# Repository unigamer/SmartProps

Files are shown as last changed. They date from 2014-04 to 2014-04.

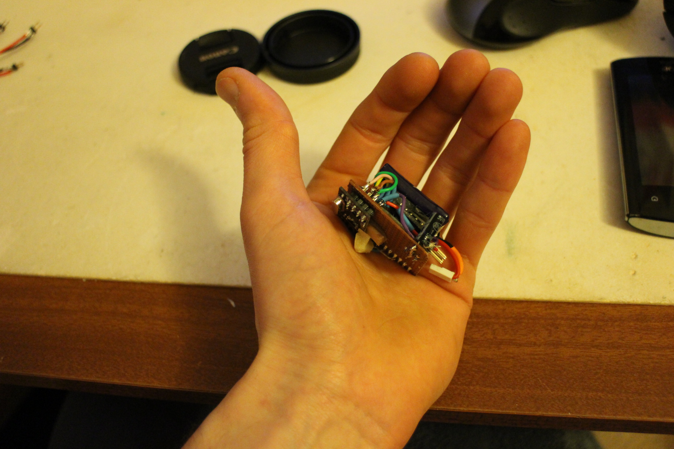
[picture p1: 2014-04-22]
Juggling Balls/Schematics/Ball PCB - Draft 1/IMG_0808.JPG

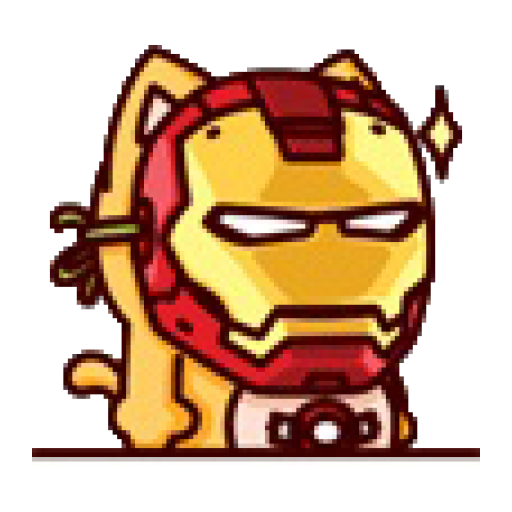
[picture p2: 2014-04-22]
Juggling Balls/Ball Control (GUI) Code/Android/ic_launcher-web.png

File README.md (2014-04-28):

SmartProps
==========

Smart LED circus props

Demo: https://www.youtube.com/watch?v=CMix5ZxQXCQ&feature=youtu.be

You want open source, smart, bluetooth enabled, LED juggling props?! Well, you're at the right place. However, this project is very much in its infancy. You can't buy any props and even making them is a bit tricky just now. I still think the code should be available so it's all here.

What can your juggling balls do?
The juggling balls are wirelessly connected and can detect if they are in your hand or in the air. A simple effect is changing colour every time they are thrown. A more advanced version is when all balls thrown at an instance change to the same random colour. The balls can flash and fade as well as staying a solid colour. All of this can be controlled through your computer or bluetooth-enabled Android phone. No more annoying button tapping to program your props! :)

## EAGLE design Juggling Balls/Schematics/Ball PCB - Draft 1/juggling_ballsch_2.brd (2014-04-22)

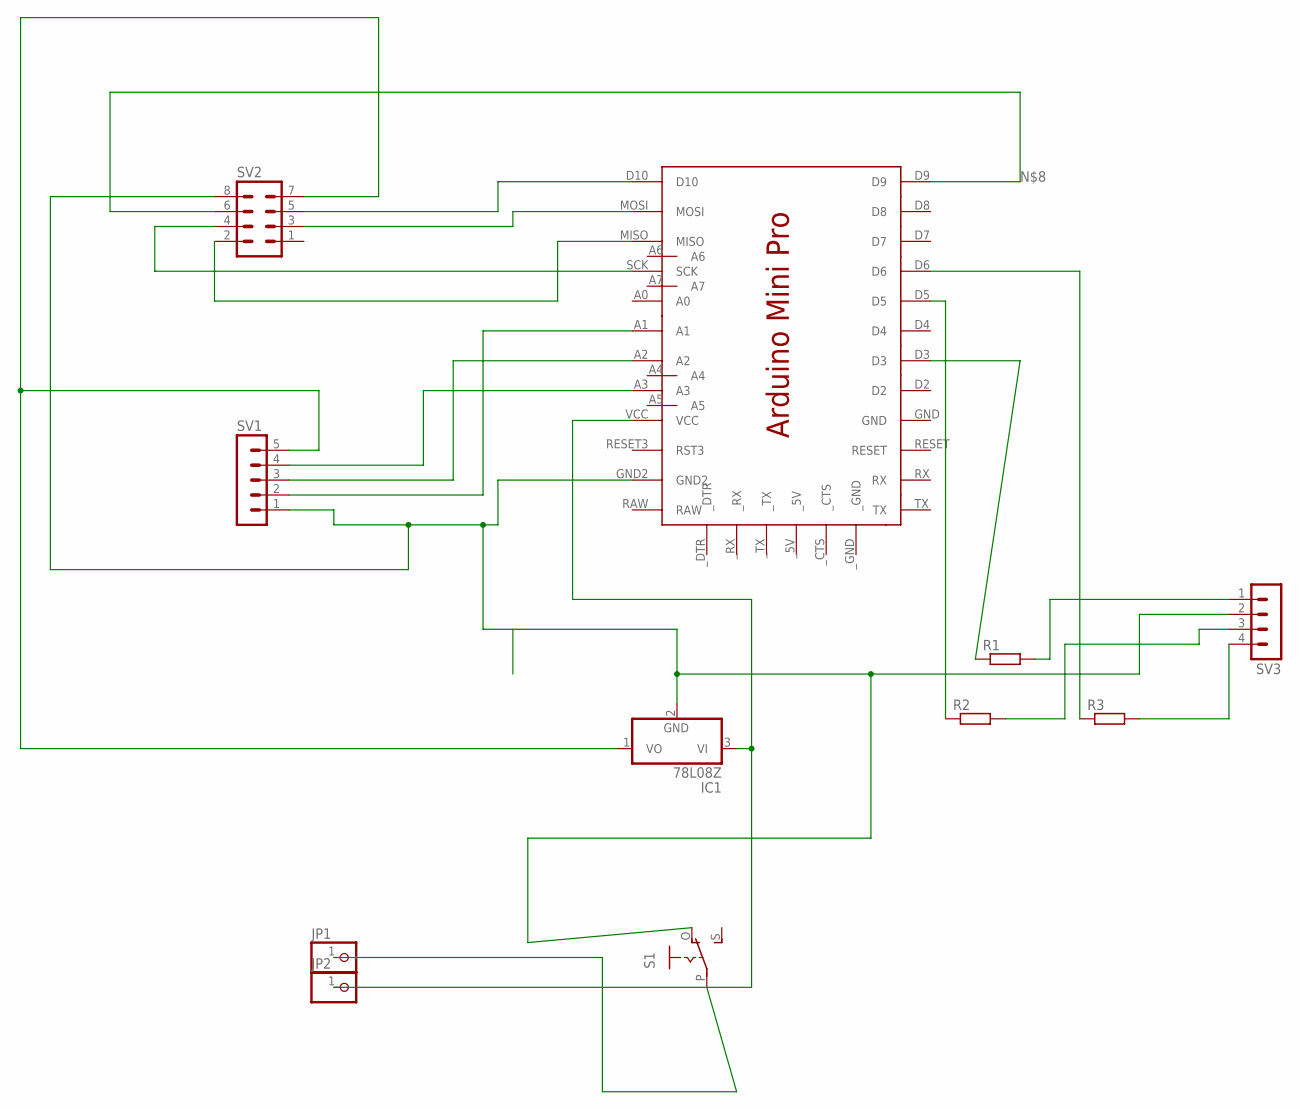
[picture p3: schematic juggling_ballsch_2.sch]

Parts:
IC1: 78L08Z; TO92
JP1, JP2: PINHD-1X1; 1X01
R1, R2, R3: R-EU_0207/7; 0207/7
S1: EG1218S; EG1218
SV1: MA05-1
SV2: MA04-2
SV3: MA04-1
U$1: ARDMINIPRO

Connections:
unnamed: SV1.2, U$1.A1
unnamed: SV1.3, U$1.A2
unnamed: SV1.4, U$1.A3
unnamed: IC1.2 (GND), S1.O, SV1.1, SV2.8, SV3.2, U$1.GND2
unnamed: SV2.3, U$1.MOSI
unnamed: SV2.5, U$1.D10
unnamed: SV2.2, U$1.MISO
unnamed: SV2.6, U$1.D9
unnamed: SV2.4, U$1.SCK
unnamed: IC1.1 (VO), SV1.5, SV2.7
unnamed: R1.1, U$1.D3
unnamed: R2.1, U$1.D5
unnamed: R3.1, U$1.D6
unnamed: R1.2, SV3.1
unnamed: R2.2, SV3.3
unnamed: R3.2, SV3.4
unnamed: JP1.1, S1.P
unnamed: IC1.3 (VI), JP2.1, U$1.VCC

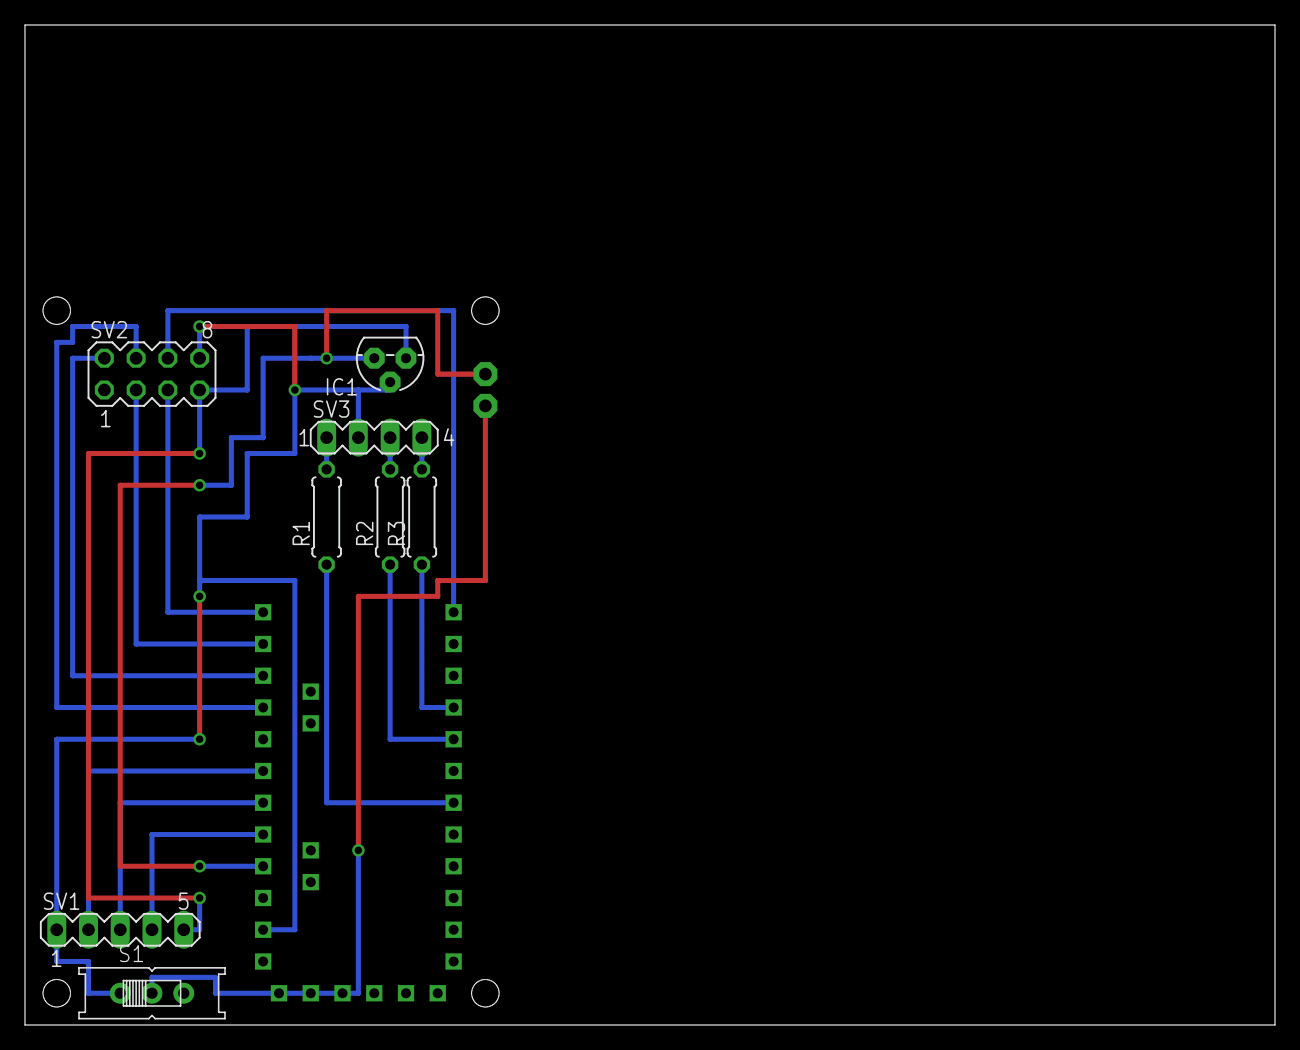
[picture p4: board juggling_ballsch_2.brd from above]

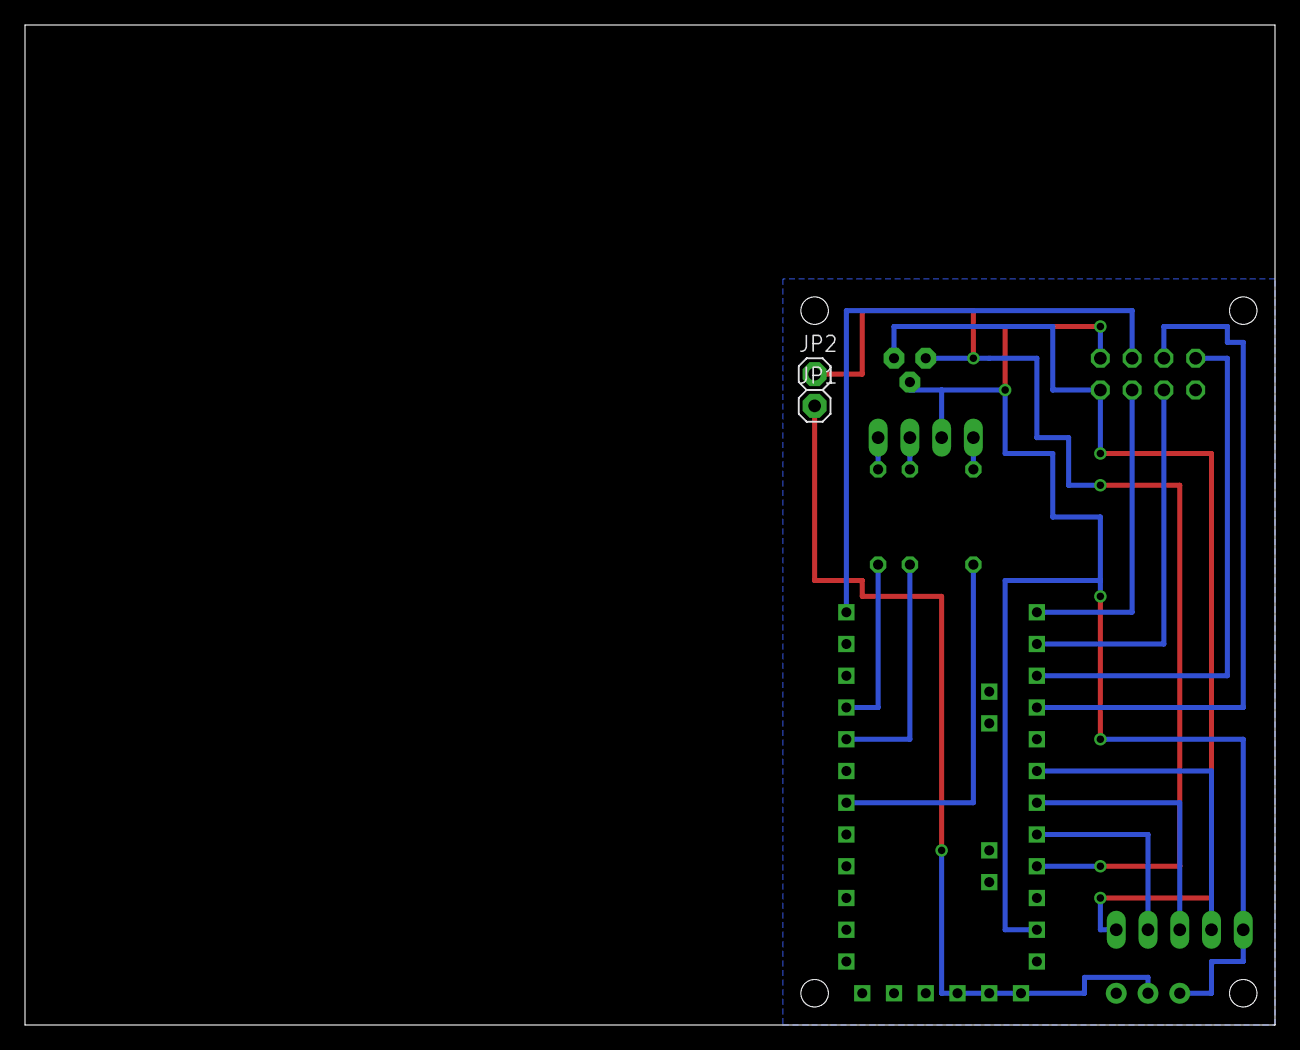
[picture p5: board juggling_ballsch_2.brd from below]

Board: 2 copper layers, 100.0 x 80.0 mm, 11 parts (2 on the bottom side), 18 nets.

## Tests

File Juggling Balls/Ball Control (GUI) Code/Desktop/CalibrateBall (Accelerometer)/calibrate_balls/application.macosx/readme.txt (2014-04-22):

This application was created on Windows, which does not
properly support setting files as "executable",
a necessity for applications on Mac OS X.

To fix this, use the Terminal on Mac OS X, and from this
directory, type the following:

chmod +x calibrate_balls.app/Contents/MacOS/JavaApplicationStub

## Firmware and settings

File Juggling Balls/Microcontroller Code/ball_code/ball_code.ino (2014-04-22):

// Juggling Ball Code
// Jonathan Jamieson
// unigamer@gmail.com
// www.jonathanjamieson.com

/*
How to send a command to a juggling ball

An ASCII string of comma seperated values should be sent either through the bluetooth>serial module or the 
USB>Serial converter on the central node. There needs to be 14 numbes terminated by a newline "/n". An
example command that would set ball number 1 to red is: 1,1,1,1,255,0,0,0,0,0,0,0,0,0

The structure is:

"1:Central Node Command Type, 2:Ball Number, 3:Ball Command Type, 4:Effect Number, 5:Red 1, 6:Green 1, 7:Blue 1, 8:Red 2, 9:Green 2, 10:Blue 2, 11:Fade Delay, 12:Send State, 13:Unused, 14: Unused"

1. Central Node Command Type = 1
2. Ball Number, currently 1,2 or 3. Alternatively, 0 can be useed to send an effect to all balls
3. Ball Command Type = 1
4. Effect Number, see below for a description of the different effects that can be used and what number to use.
5. Red 1
6. Green 1
7. Blue 1
8. Red 2
9. Green 2
10. Blue 2
11. Fade delay (measured in milliseconds)
12. Send state (0 = don't send data if ball has changed state, 1 = send data if ball changes state). Generally best to leave this = 1.
13. Currently unused but is transmitted to the ball
14. Currently unused but is transmistted to the ball



Effect Numbers
1. Solid Colour (R1, G1, B1)
2. Fade (R1 -> R2, G1 -> G2, B1 -> B2, total time = 255*Fade_Delay)
3. Fade Impact (Currently not working)
4. Fade Cycle (same as #2 Fade but goes back and forth betweem colours)
5. Flash (R1 || R2, G1 || G2, B1 || B2, Fade Delay specifies the period)
6. Send Sensor Data
7. Update Parameters
8. Disco Mode (Fade Delay specifies the period)
9. Two State (Hand: R1,G1,B1 or Air: R2,G2,B2)
10. Throw Random (no parameters needed)
11. Random Fade (Time between colours = 255*Fade_Delay)
12. Sync Throw Random
13. Two State Random
14. Sync Throw All
15. 

For another example, to fade from green to blue on ball number 2 with a a fade delay of 10ms: 1,2,1,2,0,255,0,0,0,255,10,1,0,0

*/

// Required Libraries
#include <math.h>
#include <EEPROM.h>
#include <RF24Network.h>
#include <RF24.h>
#include <SPI.h>

int ball_type; // The initial prototypes used two different kind of Pro Mini's slightly different pin layouts. This code can handle both types by setting up the pins correctly.
int random_colour_array[3];
int previous_colour_at_zero_array = 0;
// Define Pin Numbers
// Accelerometer Pins
int xpin;             
int ypin;                 
int zpin;
int accel_ground;

int command_number = 0;
boolean send_state = true;

// Set up the RF24 Communication
RF24 radio(9,10); 
RF24Network network(radio);
const uint16_t host_node = 0; // The transceiver connected to the computer is the central node. All balls are connected to it.

// Led Pins
// A common cathode tri-colour LED is required (or three individual appropraitely coloured LEDs.
const int led_r_pin = 3; // Red Pin
const int led_g_pin = 5; // Green Pin
const int led_b_pin = 6; // Blue Pin

// Payload Structure
struct payload_t
{
  int p1;
  int p2;
  int p3;
  int p4;
  int p5;
  int p6;
  int p7;
  int p8;
  int p9;
  int p10;
//  int p11;
//  int p12;
};

payload_t payload_rx;
payload_t payload_tx;

// This filter is used to smooth the magnitude of the acceleration output
#define filterSamples   17  // Filter Samples should  be an odd number, no smaller than 3
int sensSmoothArray1[filterSamples];  
int smoothmag;  

int x; // Acceleration in the x-direction
int y; // Acceleration in the y-direction
int z; // Acceleration in the z-direction

double magnitude_accelerometer;

// These values are used to scale the acceleration that is read from the accelerometer. This is required because the voltage varies as the Lipo drains down.
int xMin;
int yMin;
int zMin;
int xMax;
int yMax;
int zMax;

int ball_number; // The number of this ball. Must be unique and between 1-5 inclusive.

int colour_array[2][3];

int state_ball = 0; // 0=hand, 1=air
boolean new_command = true;

unsigned long time;
unsigned long time_2;

int fade_counter = 0; 
int fade_delay = 5; // (ms)
int fade_decrement = 1;
int effect_impact = 35;

int effect_direction = 1; //1== forwards, 0 = backwards

unsigned long impact_time;
int impact_minimum_time = 320;
int impact_minimum_mag = 15;
int impact_average_mag = 9;  // currently not using this average crap

int flag_ball=0;
boolean flag_change_state = 0;

int effect_number = 1;
void setup(void)
{

  // Get Data from EEPROM. Each ball is a "node" with a unique number. The central receiver (node 0) is connected to a computer and is not actually a juggling ball.
  // The EEPROM data is set using, ball_write_eeprom.pde.
  ball_number = EEPROM.read(0);
  effect_number = EEPROM.read(1); // Which effect to start off with. This should be 1 (Solid Colour) under normal circumstances.
  colour_array[0][0] = EEPROM.read(2); // Red PWM to start with
  colour_array[0][1] = EEPROM.read(3); // Green PWM to start with
  colour_array[0][2] = EEPROM.read(4); // Blue PWM to start with

  // Determine which Arduino type to use
  ball_type = EEPROM.read(5);

  // Get the scaling values of the acceleration readings. The multiplication by 4 is because only 0-225 can be sent so it's divided by 4 before being transmitted to the ball and then reconstructed here.
  xMin = EEPROM.read(6)*4; 
  yMin = EEPROM.read(7)*4;
  zMin = EEPROM.read(8)*4;
  xMax = EEPROM.read(9)*4;
  yMax = EEPROM.read(10)*4;
  zMax = EEPROM.read(11)*4;

  // Derek Lang Style
  if (ball_type==1) {
    xpin = A1;
    ypin = A2;
    zpin = A3;
    Serial.print("Ball type 1");

    // Jianlin's style
  } 
  else if (ball_type==2) {
    xpin = A0;
    ypin = A1;
    zpin = A2;
    Serial.print("Ball type 2");
    pinMode(A3, OUTPUT);
    digitalWrite(A3, LOW); 
  }

  // Set Accelerometer pins as inputs
  pinMode(xpin, INPUT);
  pinMode(ypin, INPUT);
  pinMode(zpin, INPUT);

  // Start communications with RF24
  SPI.begin();
  radio.begin();
  network.begin(90,ball_number);
  radio.setRetries(15,1);

  // Transmit ball details through serial
  Serial.begin(57600);

  Serial.print("This is juggling ball number: ");
  Serial.print(ball_number);
  Serial.println("");

  Serial.println(xMin);
  Serial.println(yMin);
  Serial.println(zMin);
  Serial.println(xMax);
  Serial.println(yMax);
  Serial.println(zMax);
}

void loop(void)
{
  check_for_new_command();
  check_ball_state();
  process_effect();
}

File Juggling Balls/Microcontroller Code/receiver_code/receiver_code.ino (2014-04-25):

// Juggling Ball Central Node Code
// Jonathan Jamieson
// unigamer@gmail.com

// www.jonathanjamieson.com

/* 
 This is the code for the central node is attached to the computer and/or connected to a bluetooth device
 such as your phone. The central node contains the following hardware: Arduino (I use a Pro Mini + USB>Serial
 adapter, NRF24L01 (2.4Ghz Transceiver), Bluetooth Serial Module and an IR LED to trigger a camera (optional).
 
 The Bluetooth adapter is attached to Pins 2 & 3 for me using the Software Serial library. However, any suitable
 unused digital pins can be used. I have the Software Serial running at the same baud rate as the actual serial
 port (57600) but you can change this if desired. Remember that your Bluetooth Serial Module will need to be
 configured to run at the same speed as the software serial (default speed is 9600 on most modules). The RX pin
 on the Bluetooth should be connected to Pin 2 and Bluetooth TX should be Pin 3.
 
 The wiring for the NRF24L01 is as follows (courtesy of http://arduino-info.wikispaces.com/Nrf24L01-2.4GHz-HowTo):
 
 RF Module      Arduino Pin
 GND (1)        GND
 VCC (2)        3.3v (I used the USB>Serial 3.3v because Pro Mini's don't have an on board regulator)
 CE (3)         9
 CSN (4)        10
 SCK (5)        13
 MOSI (6)       11
 MISO (7)       12
 IRQ(8)         UNUSED
 
 
 I used the more expensive nRF24L01 + Antenna for this central node because I have found it significantly improves
 the range (http://cgi.ebay.co.uk/ws/eBayISAPI.dll?ViewItem&item=131128076671&ssPageName=ADME:L:OC:GB:3160).
 However, you can use the cheaper <$2 module if you're on a budget or need to save space. I use the cheap modules
 in the balls and haven't had any problems.
 
 */

// Required Libraries
#include <RF24Network.h>
#include <RF24.h>
#include <SPI.h>
#include <SoftwareSerial.h>
#include <multiCameraIrControl.h>

Canon D5(4); // Annode of IR LED on Pin 4
RF24 radio(9,10);
RF24Network network(radio);
SoftwareSerial mySerial(3, 2); // RX, TX

const uint16_t this_node = 0; // Address of our node

int ball_number; // Address of the other node
int ball_numbers[] = {
  1,2,3}; // An array of the ball numbers that can be available (However, they don't NEED to be available)
const int num_balls = 3; // This should be the number of elements in the ball_numbers array

// Stuff for received serial commands
const int NUMBER_OF_FIELDS = 14; // how many comma separated fields we expect
int fieldIndex = 0;            // the current field being received
int values[NUMBER_OF_FIELDS];   // array holding values for all the fields

int balls_effects[num_balls]; // A ball is currently in this mode then it's element should =1, else it should =0
int sync_colour_1[3];
int sync_colour_2[3];
int previous_colour_at_zero_array = 0;
int random_colour_array[3];

unsigned long sync_throw_time;
int sync_throw_tolerance = 150;
// Payload Structure
struct payload_t
{
  int p1;
  int p2;
  int p3;
  int p4;
  int p5;
  int p6;
  int p7;
  int p8;
  int p9;
  int p10;
  // int p11;
  // int p12;
};

payload_t payload_rx;
payload_t payload_tx;

void setup(void)
{
  Serial.begin(57600);
  SPI.begin();
  radio.begin();
  network.begin(/*channel*/ 90, /*node address*/ this_node);

  pinMode(A3, OUTPUT); // I used A3 as the GND for my IR LED
  digitalWrite(A3, LOW); 

  mySerial.begin(57600); // MAKE SURE YOUR BLUETOOTH SERIAL MODULE IS CONFIGURED TO WHATEVER SPEED IS HERE!
  mySerial.println("Unleash the power of your smart balls!");
}

void loop(void)
{
  // Pump the network regularly
  network.update();

  while ( network.available() ) // Check network to see if the balls have anything to say
  {
    // If so, grab it and print it out
    RF24NetworkHeader header;
    payload_t payload;
    network.read(header,&payload,sizeof(payload)); 

    payload_rx = payload;
    Serial.print("1"); // type of command
    Serial.print(","); 
    Serial.print(payload_rx.p1); 
    Serial.print(","); 
    Serial.print(payload_rx.p2); 
    Serial.print(",");
    Serial.print(payload_rx.p3); 
    Serial.print(",");
    Serial.print(payload_rx.p4);
    Serial.println("");

    if (balls_effects[payload.p1-1]==12 && payload.p3==1) { // If the ball has just been thrown and it's effect type is Sync Throw Random then we need to send it a new colour
    
    ball_number = payload.p1;
      process_sync_throw();
    }
    
    
    
   if (balls_effects[payload.p1-1]==14 && payload.p3==1) { // If the ball has just been thrown and it's effect type is Throw Sync (All) then we need to a new colour to all the balls
      process_sync_throw_all();
    }
    
    
  }

  check_serial(); // Check to see if any serial command is available from either the Bluetooth or USB
}


void serial_command_to_ball() {
  if (values[1] == 0) { // send command to all balls if ball number is zero
    for (int destination_node = 0; destination_node < num_balls; destination_node++)  {
      send_payload(ball_numbers[destination_node]);   


    }
  } 
  else {

    // send command to ball_number values[1]
    send_payload(values[1]);
  }

}


void send_payload(int destination_node) {



  //  Serial.println("");
  ball_number = destination_node;
  payload_tx.p1 = values[2]; // Type of command
  payload_tx.p2 = values[3]; // Effect type if type of command = 1
  payload_tx.p3 = values[4];
  payload_tx.p4 = values[5];
  payload_tx.p5 = values[6];
  payload_tx.p6 = values[7];
  payload_tx.p7= values[8];
  payload_tx.p8 = values[9];
  payload_tx.p9 = values[10];
  payload_tx.p10 = values[11];
  //    payload_tx.p11 = values[12];
  //     payload_tx.p12 = values[13];
  payload_t payload;
  payload = payload_tx;
  RF24NetworkHeader header(ball_number);
  bool ok = network.write(header,&payload,sizeof(payload));

  balls_effects[ball_number-1] = values[3];

} 

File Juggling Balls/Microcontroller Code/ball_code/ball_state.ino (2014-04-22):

void check_ball_state() {

  // Accelerometer Stuff. This is all about detecting if the ball is in your hand on in the air.
  // Check Accelerometer
  x = analogRead(xpin); 
  delay(1); 
  y = analogRead(ypin); 
  delay(1); 
  z = analogRead(zpin);

  // Scale Acceleromater Readings. Use calibration program to set xMin, xMax etc
  int xAng = map(x, xMin, xMax, -90, 90);
  int yAng = map(y, yMin, yMax, -90, 90);
  int zAng = map(z, zMin, zMax, -90, 90);

  magnitude_accelerometer = sqrt(pow(xAng,2)+pow(yAng,2)+pow(zAng,2)); // Determine the magnitude of the acceleration
  smoothmag = digitalSmooth(magnitude_accelerometer, sensSmoothArray1); // Filter the magnitude because it's a noisy signal

  // If ball state is set as in hand, see if now in air
  if (smoothmag<40 && flag_ball==0 && state_ball==0) {
    impact_time = millis() +60;
    flag_ball= 1;
    //Serial.println("Suspect Ball now in air");
  }

  // If ball state is set as in air, see if now in hand
  if (smoothmag>40 && flag_ball==0 && state_ball==1) {
    impact_time = millis() +60;
    flag_ball= 1;
    //Serial.println("Suspect Ball now in hand");
  }

  // If 60ms has past and it's still recorded as a change in state then accept that it really has
  if (millis()>impact_time && flag_ball==1) {
    // Serial.println("Checking ball state because time check reached");

    // Check if ball now in AIR
    if (state_ball==0 && smoothmag<40) {

      command_number = command_number+1;

      //  Serial.println("This ball is definitely in the air!!!!!");
      state_ball=1;
      flag_ball=0;

      if(send_state) {
        payload_tx.p1 = ball_number;
        payload_tx.p2 = magnitude_accelerometer;
        payload_tx.p3 = 1; // in air
        payload_tx.p4 = command_number;
        payload_t payload;
        payload = payload_tx;
        RF24NetworkHeader header(host_node);
        bool ok = network.write(header,&payload,sizeof(payload));
      }
      flag_change_state = true;
    } 
    else {
      // 60ms has past and it seems the ball has not actually changed state so it's a false positive
      flag_ball = 0;
    }

    // Check if ball now in HAND
    if (state_ball==1 && smoothmag>40) {

      command_number = command_number+1;

      // Serial.println("This ball is definitely in the hand!!!!!");
      state_ball=0;
      flag_ball=0;

     if(send_state) {
      payload_tx.p1 = ball_number;
      payload_tx.p2 = magnitude_accelerometer;
      payload_tx.p3 = 0; // in air
      payload_tx.p4 = command_number;
      payload_t payload;
      payload = payload_tx;

      RF24NetworkHeader header(host_node);
      bool ok = network.write(header,&payload,sizeof(payload));
      flag_change_state = true;
     }
    } 
    else {
      // 60ms has past and it seems the ball has not actually changed state so it's a false positive
      flag_ball = 0;
    }
  }

}

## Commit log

2014-04-22 First bulk upload of code
    This is the first major upload of code. Not exactly well tested, but it
    should all be here!
    [juggling_ballsch.brd, juggling_ballsch.sch, juggling_ballsch_2.brd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]
2014-04-22 Change some folder names
    Fiddling around with stuff
    [juggling_ballsch.brd, juggling_ballsch.sch, juggling_ballsch_2.brd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]
2014-04-25 Fixed "Throw Random Sync"
    I had moved Throw Random Sync to effects.ino and because it was outisde
    the main loop payload_tx.p1 wasn't available so the colour wasn't being
    sent back to the ball.
    Should be fixed now.
    [effects.ino, receiver_code.ino]
